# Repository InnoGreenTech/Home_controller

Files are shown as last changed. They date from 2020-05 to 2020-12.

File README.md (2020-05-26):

# Home_controller
Home controller allow to pilote the VMC.  For this it reads the CO2, Humidity and temperature. It is able also forecast the Weather. It have a touch screen.

Description:
------------

Home controller allow to pilote a VMC. It use a MH-Z19B sensor to measure the C02 and DHT22 for humidity and temperature in the pipe of the ventilation.
A BME280 allow to measure humidity, temperature and pressure in out door, like this is possible to forecaste weather.

There are a main card with a touch screen and a remote VMC.

Also ther is another modul to measure the power consomation of the house. Is it possible to read them in real time.

A optional ESP8266, allow to sent data with a Json file and it is possible to connect at a webpage with evry information.

[*You can found more information on my web site on this page*](https://innogreentech.fr/fr/objets-connectes/mesures/70-controleur-de-vmc)

I share also the drawing, the pcb, and the box designe in this repository.

Screen interface:
----------------
Picture of current status

Remote VMC:
----------------

Picture of current status

Remote energie meter:
----------------

Picture of current status

Contributing:
-------------

Fork it.
Create your feature branch (git checkout -b my-new-feature).
Commit your changes (git commit -am 'Add some feature').
Push to the branch (git push origin my-new-feature).
Create new Pull Request.

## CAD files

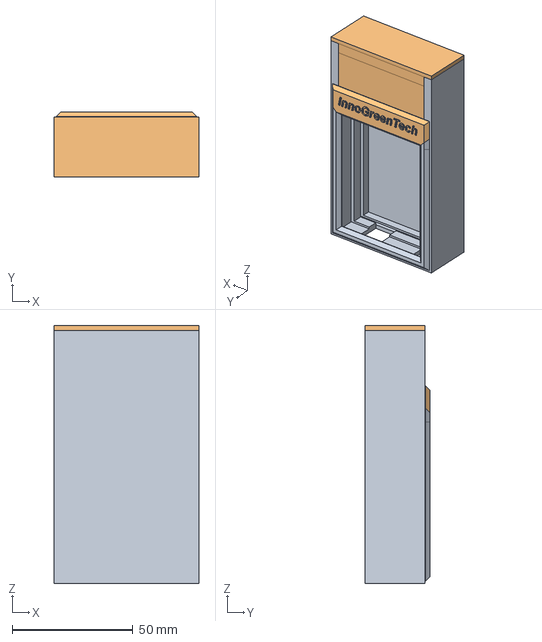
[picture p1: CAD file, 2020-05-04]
Main_board/Drawing and 3D files/box_main_card_home_controller.FCStd
60.0 x 27.0 x 107.0 mm
Bouchon

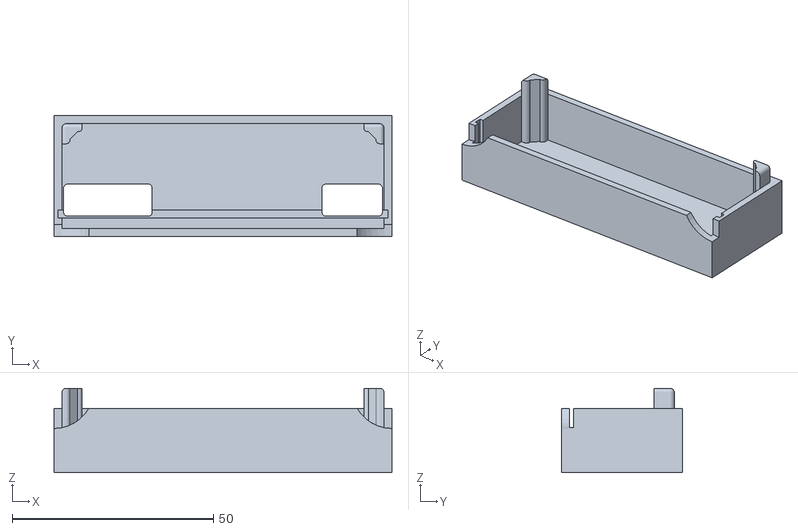
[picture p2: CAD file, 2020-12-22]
Board_VMC_home/3D_printer_files/Cache box carte VMC..stl
84.0 x 30.0 x 21.0

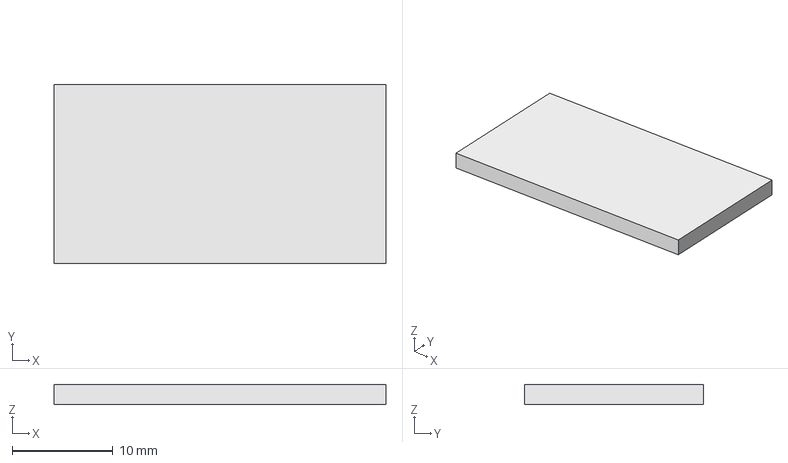
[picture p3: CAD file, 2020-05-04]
Energy_meter/Drawing_energy_meter/Fichier 3D/3D_compteur_energie.FCStd
33.0 x 17.8 x 2.00 mm

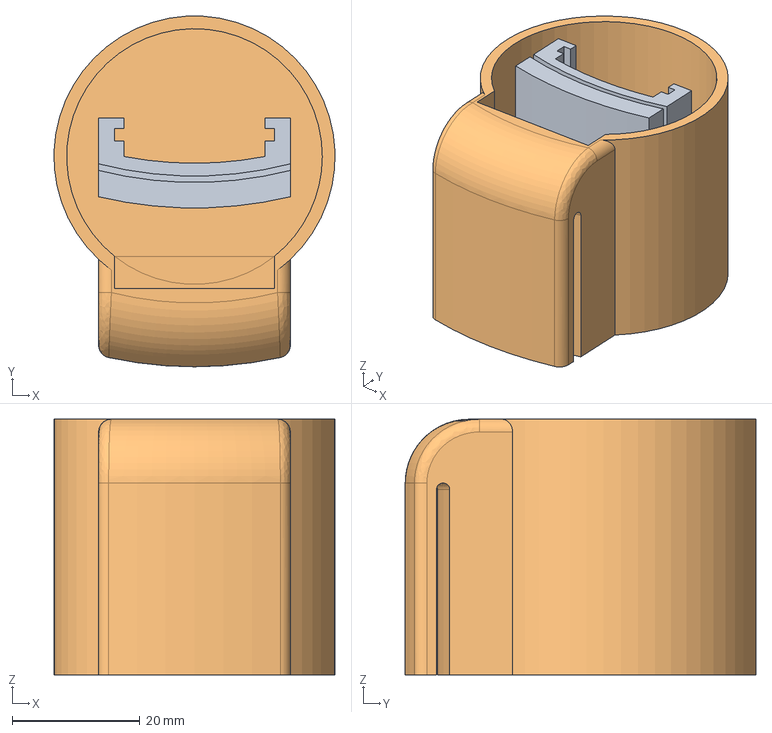
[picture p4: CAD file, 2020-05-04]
Board_VMC_home/3D_printer_files/probe_vmc_support.FCStd
44.0 x 54.9 x 40.0 mm

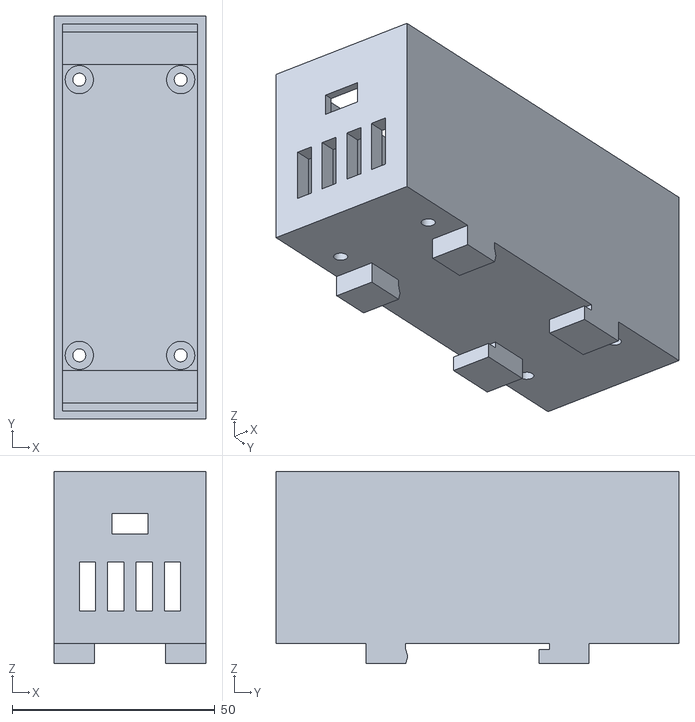
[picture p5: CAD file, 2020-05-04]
Energy_meter/Drawing_energy_meter/Fichier 3D/corp_module.stl
37.4 x 99.4 x 47.4

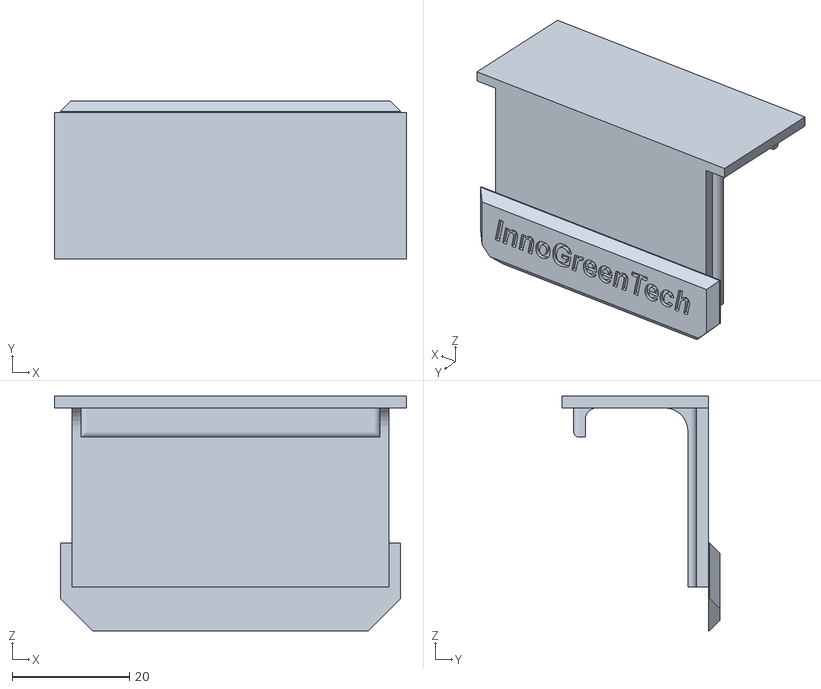
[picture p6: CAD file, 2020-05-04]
Main_board/Drawing and 3D files/closer_home_controller.stl
60.0 x 27.0 x 40.0

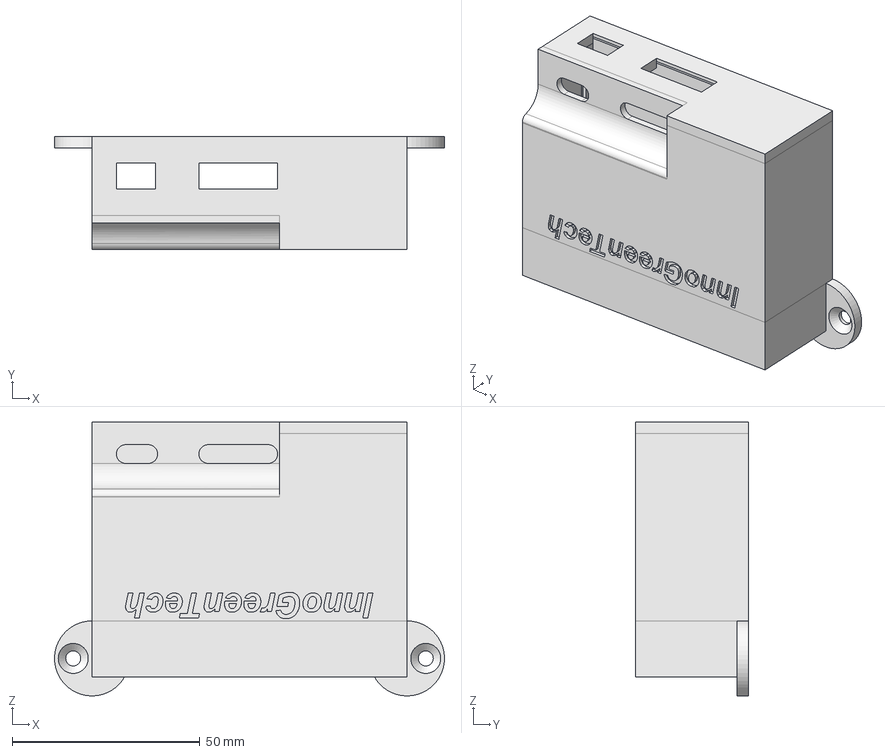
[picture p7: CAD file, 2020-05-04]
Board_VMC_home/3D_printer_files/vmc_card_box.FCStd
104.0 x 30.0 x 73.0 mm

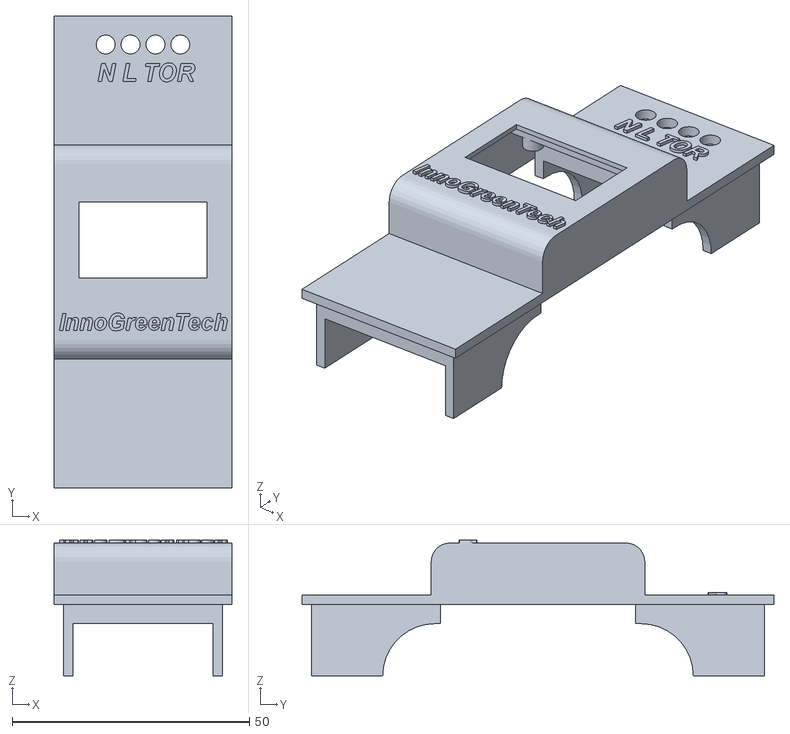
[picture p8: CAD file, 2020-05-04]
Energy_meter/Drawing_energy_meter/Fichier 3D/couvercle_module.stl
37.4 x 99.4 x 28.6

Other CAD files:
Board_VMC_home/3D_printer_files/VMC_card_box.stl
Board_VMC_home/3D_printer_files/probe_vmc_support.stl
Main_board/Drawing and 3D files/box_main_card_home_controller.stl

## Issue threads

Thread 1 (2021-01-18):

salut

cybermandiant, 2021-01-18:
salut super beau projet seulement je bloque sur la librairie manquante  <Fonts/WeatherIcon.h>
dans le dossier Main board le croqui ne veux pas ce compiler :( car il manque ce fichier

InnoGreenTech, 2021-01-21:
Bonjour,
Il faut récupérer le font ici: https://github.com/kaldoran/Adafruit-Weather-Icon/blob/master/WeatherIcon.h  Ensuite installer le fichier sous le répertoire Adafruit_GFX_Library\Fonts de la bibliothèque d'Ada-fruit.

cybermandiant, 2021-01-21:
Bonsoir super merci beaucoup pour la reponse :)

Closed 2021-01-21.

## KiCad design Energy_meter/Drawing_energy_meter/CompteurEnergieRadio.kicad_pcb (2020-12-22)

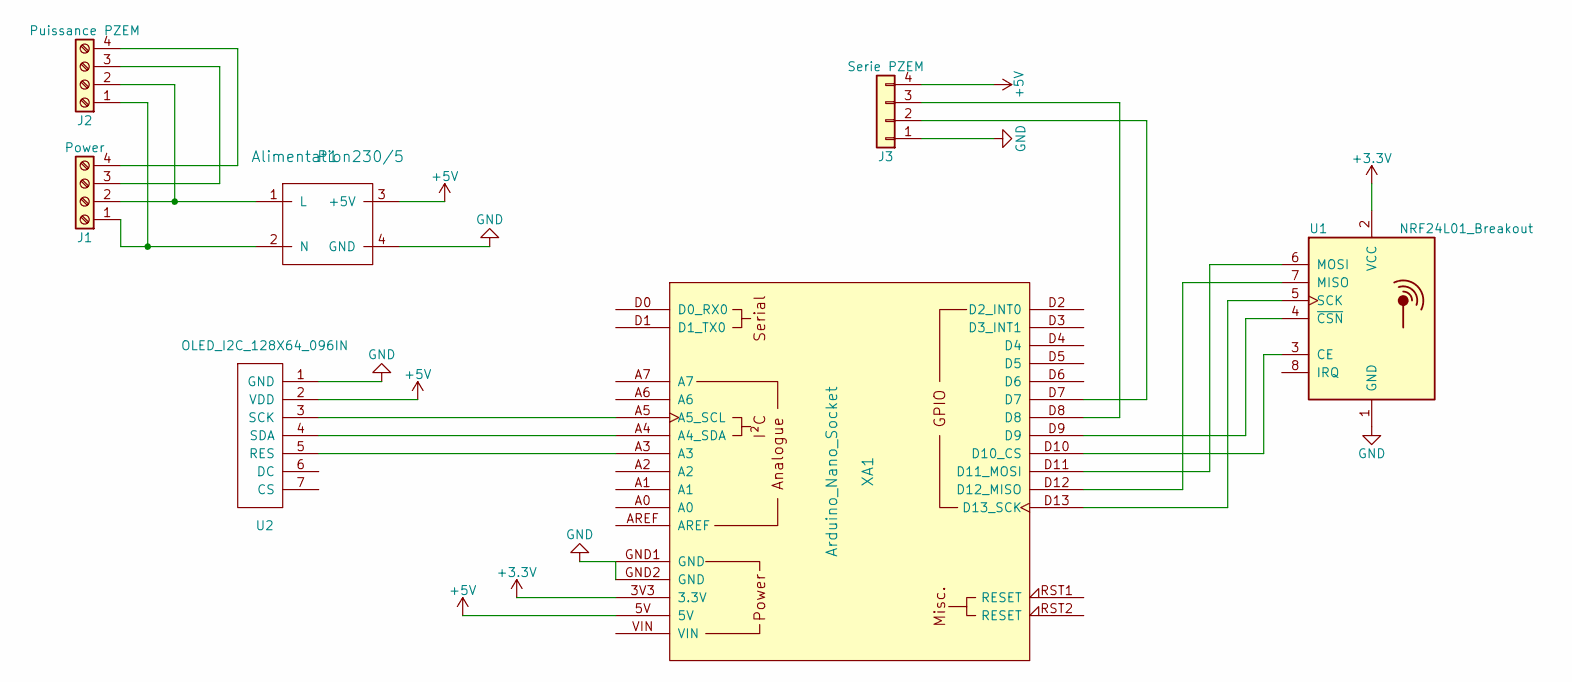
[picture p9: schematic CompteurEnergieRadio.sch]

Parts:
J1: Power; TerminalBlock_bornier-4_P5.08mm
J2: Puissance PZEM; TerminalBlock_bornier-4_P5.08mm
J3: Serie PZEM; JST_EH_B04B-EH-A_04x2.50mm_Straight
P1: Alimentation230/5; Alimentation5V
U1: NRF24L01_Breakout; nRF24L01_Breakout
U2: OLED_I2C_128X64_096IN; 96OLEDV2
XA1: Arduino_Nano_Socket; Arduino_Nano_2

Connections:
+3V3: U1.2 (VCC), XA1.3V3 (3.3V)
+5V: J3.4, P1.3 (+5V), U2.2 (VDD), XA1.5V
GND: J3.1, P1.4 (GND), U1.1 (GND), U2.1 (GND), XA1.GND1 (GND), XA1.GND2 (GND)
unnamed: J1.1, J2.1, P1.2 (N)
unnamed: J1.2, J2.2, P1.1 (L)
unnamed: J1.3, J2.3
unnamed: J1.4, J2.4
unnamed: J3.2, XA1.D7
unnamed: J3.3, XA1.D8
unnamed: U1.3 (CE), XA1.D10 (D10_CS)
unnamed: U1.4 (~CSN), XA1.D9
unnamed: U1.5 (SCK), XA1.D13 (D13_SCK)
unnamed: U1.6 (MOSI), XA1.D11 (D11_MOSI)
unnamed: U1.7 (MISO), XA1.D12 (D12_MISO)
unnamed: U2.3 (SCK), XA1.A5 (A5_SCL)
unnamed: U2.4 (SDA), XA1.A4 (A4_SDA)
unnamed: U2.5 (RES), XA1.A3

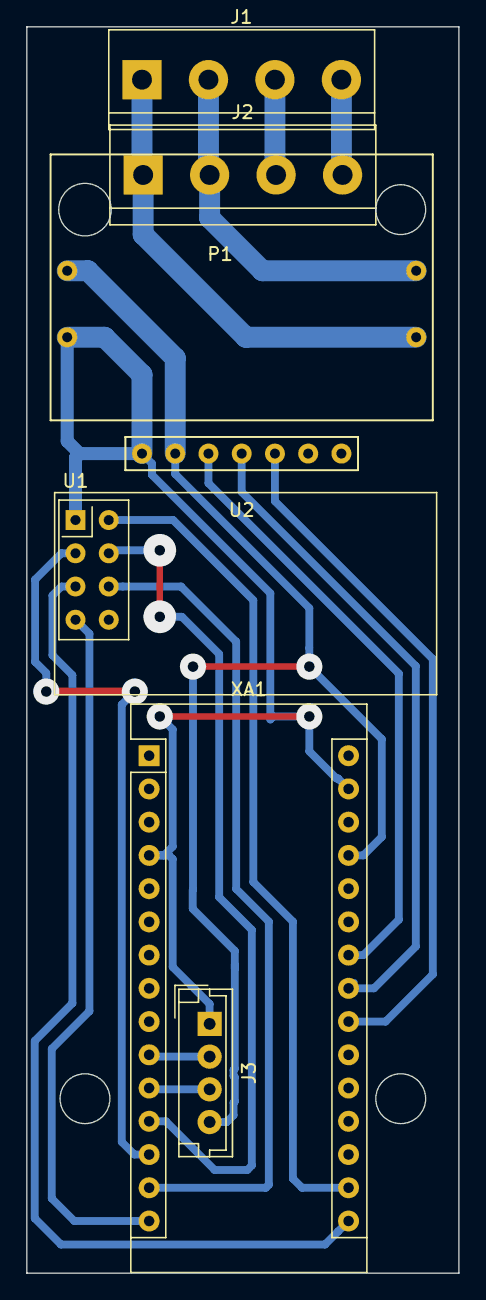
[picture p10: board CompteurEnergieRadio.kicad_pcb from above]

Board: 2 copper layers, 33.0 x 95.3 mm, 7 parts (0 on the bottom side), 17 nets.

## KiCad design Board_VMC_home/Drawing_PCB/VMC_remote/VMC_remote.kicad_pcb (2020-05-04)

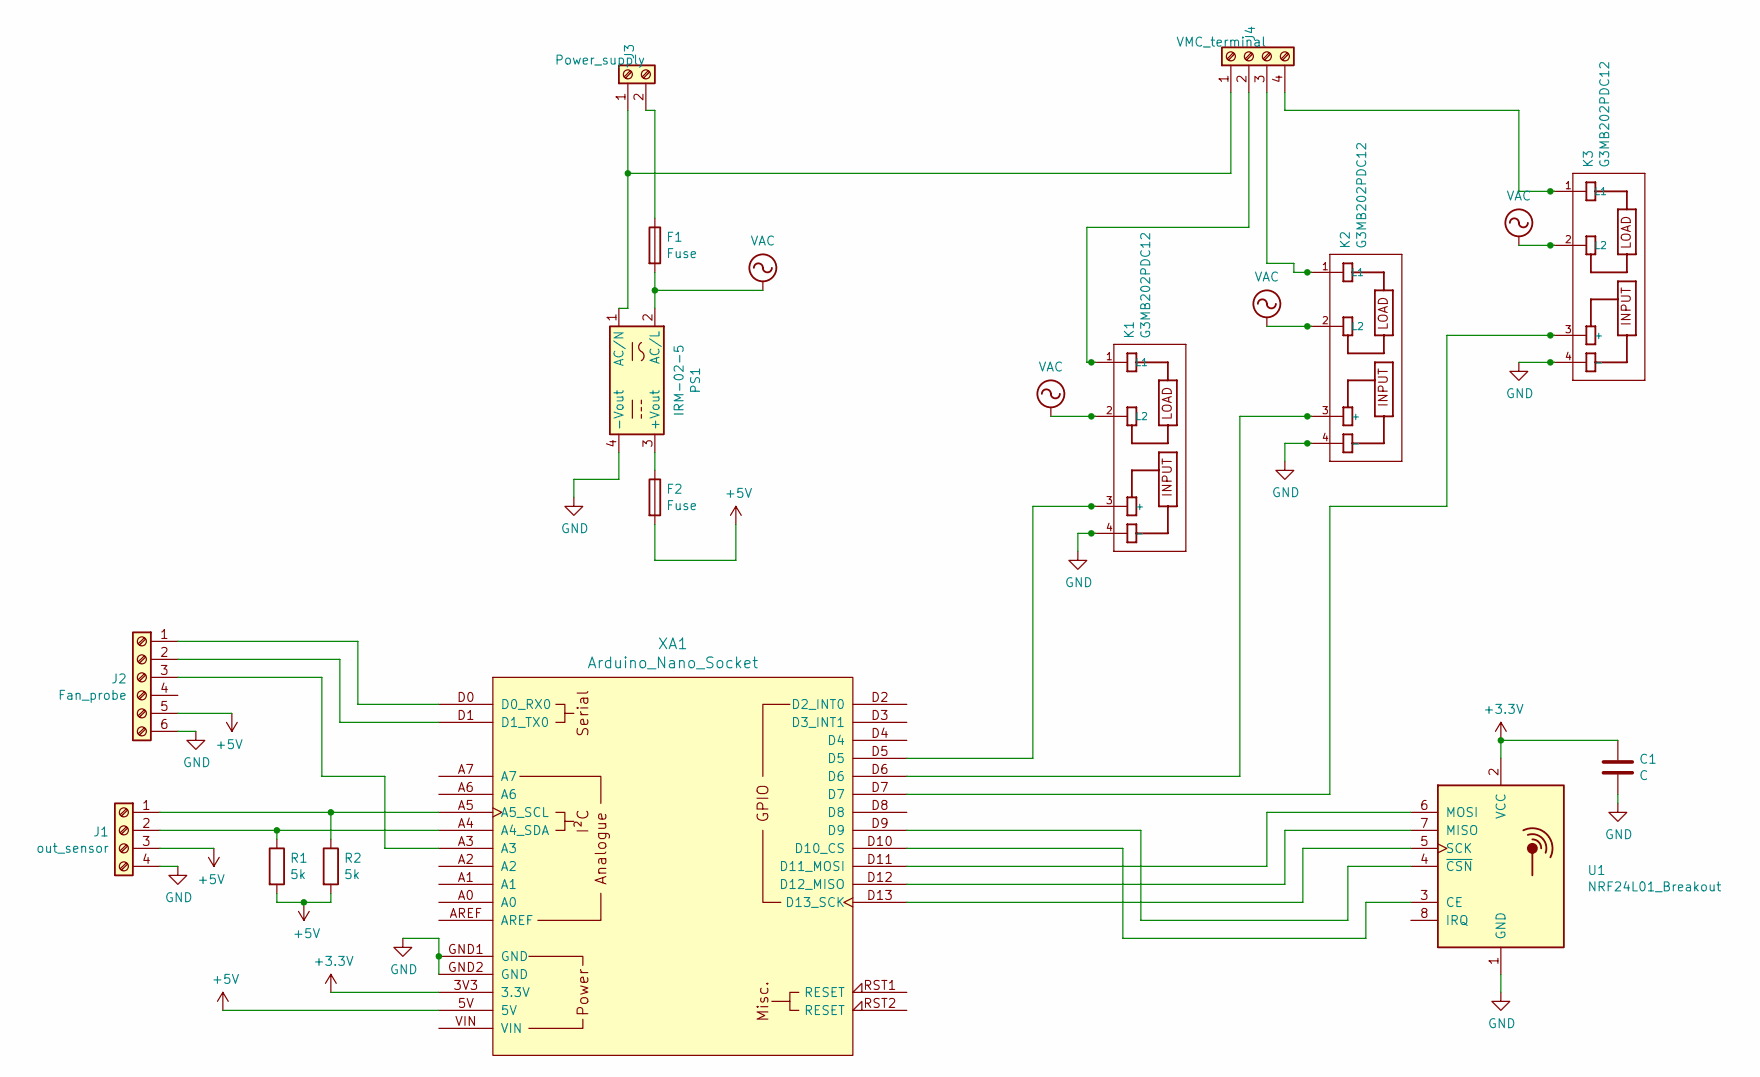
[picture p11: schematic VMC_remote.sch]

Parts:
C1: C; C_Disc_D7.0mm_W2.5mm_P5.00mm
F1, F2: Fuse; R_Axial_DIN0516_L15.5mm_D5.0mm_P20.32mm_Horizontal
J1: out_sensor; TerminalBlock_4Ucon_1x04_P3.50mm_Horizontal
J2: Fan_probe; TerminalBlock_4Ucon_1x06_P3.50mm_Horizontal
J3: Power_supply; TerminalBlock_bornier-2_P5.08mm
J4: VMC_terminal; TerminalBlock_bornier-4_P5.08mm
K1, K2, K3: G3MB202PDC12; RELAY_G3MB202PDC12
PS1: IRM-02-5; Converter_ACDC_MeanWell_IRM-02-xx_THT
R1, R2: 5k; R_Axial_DIN0411_L9.9mm_D3.6mm_P12.70mm_Horizontal
U1: NRF24L01_Breakout; nRF24L01_Breakout
XA1: Arduino_Nano_Socket

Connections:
+3V3: C1.1, U1.2 (VCC), XA1.3V3 (3.3V)
+5V: F2.2, J1.3, J2.5, R1.2, R2.2, XA1.5V
GND: C1.2, J1.4, J2.6, K1.4 (-), K2.4 (-), K3.4 (-), PS1.4 (-Vout), U1.1 (GND), XA1.GND1 (GND), XA1.GND2 (GND)
unnamed: F1.1, J3.2
unnamed: F2.1, PS1.3 (+Vout)
unnamed: J1.1, R2.1, XA1.A5 (A5_SCL)
unnamed: J1.2, R1.1, XA1.A4 (A4_SDA)
unnamed: J2.1, XA1.D0 (D0_RX0)
unnamed: J2.2, XA1.D1 (D1_TX0)
unnamed: J2.3, XA1.A3
unnamed: J3.1, J4.1, PS1.1 (AC/N)
unnamed: J4.2, K1.1 (L1)
unnamed: J4.3, K2.1 (L1)
unnamed: J4.4, K3.1 (L1)
unnamed: K1.3 (+), XA1.D5
unnamed: K2.3 (+), XA1.D6
unnamed: K3.3 (+), XA1.D7
unnamed: U1.3 (CE), XA1.D10 (D10_CS)
unnamed: U1.4 (~CSN), XA1.D9
unnamed: U1.5 (SCK), XA1.D13 (D13_SCK)
unnamed: U1.6 (MOSI), XA1.D11 (D11_MOSI)
unnamed: U1.7 (MISO), XA1.D12 (D12_MISO)
VAC: F1.2, K1.2 (L2), K2.2 (L2), K3.2 (L2), PS1.2 (AC/L)

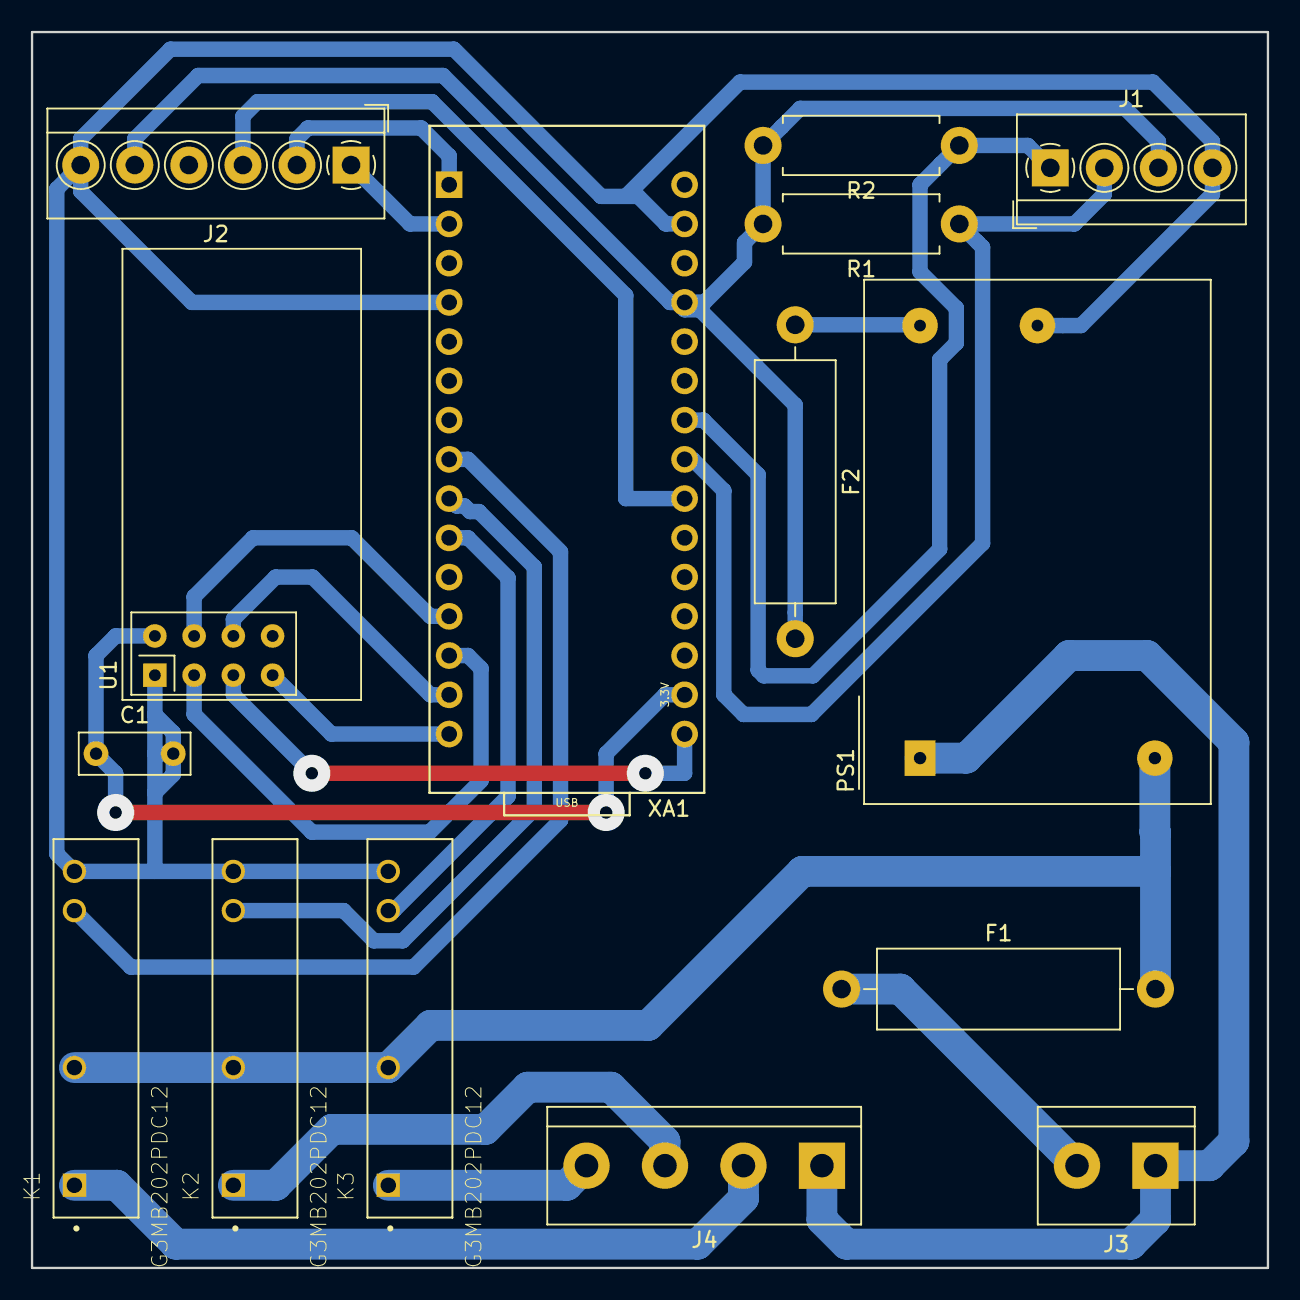
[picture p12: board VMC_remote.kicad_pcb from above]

Board: 2 copper layers, 80.0 x 80.0 mm, 15 parts (0 on the bottom side), 23 nets.

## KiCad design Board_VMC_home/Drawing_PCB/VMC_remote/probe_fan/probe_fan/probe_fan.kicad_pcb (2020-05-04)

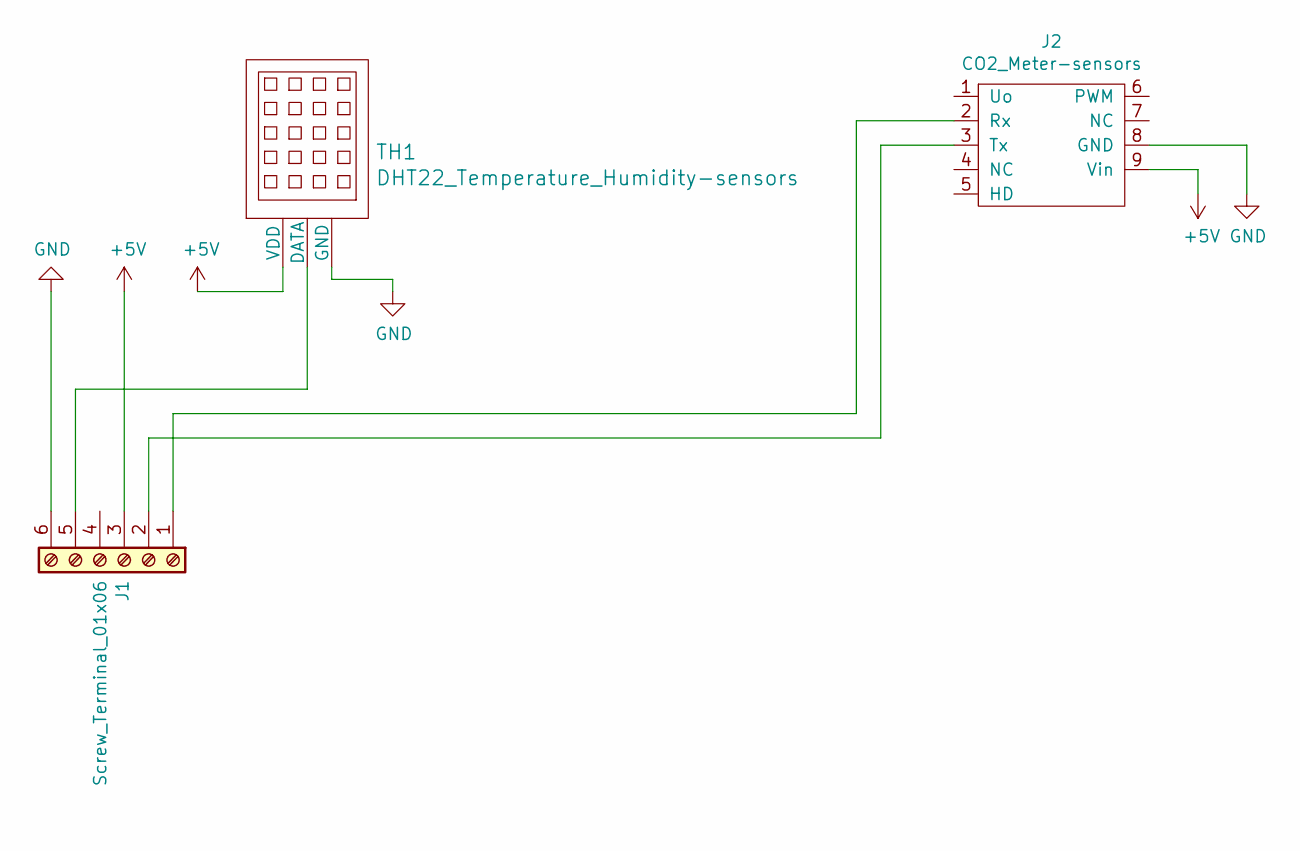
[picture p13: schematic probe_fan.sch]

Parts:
J1: Screw_Terminal_01x06; TerminalBlock_MetzConnect_Type059_RT06306HBWC_1x06_P3.50mm_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
J2: CO2_Meter-sensors; MHZ19B
TH1: DHT22_Temperature_Humidity-sensors; DHT22_Temperature_Humidity

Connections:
+5V: J1.3, J2.9 (Vin), TH1.1 (VDD)
GND: J1.6, J2.8 (GND), TH1.3 (GND)
unnamed: J1.1, J2.2 (Rx)
unnamed: J1.2, J2.3 (Tx)
unnamed: J1.5, TH1.2 (DATA)

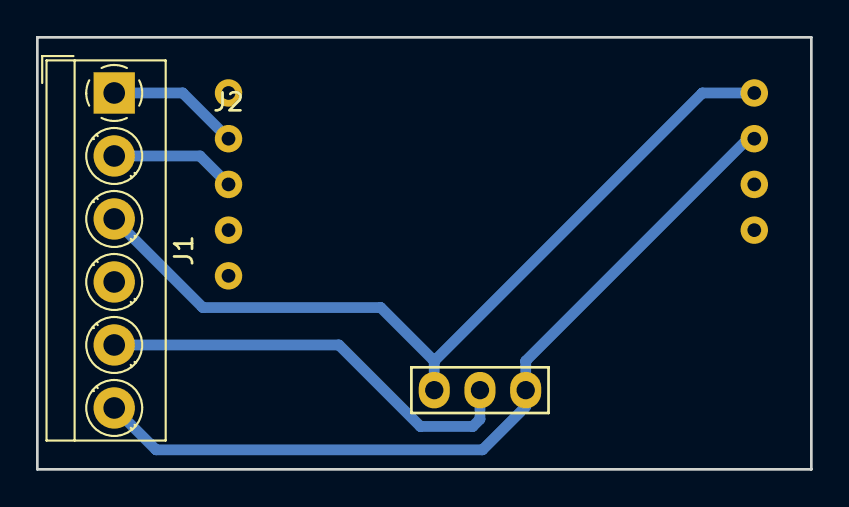
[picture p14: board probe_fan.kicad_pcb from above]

Board: 2 copper layers, 43.0 x 24.0 mm, 3 parts (0 on the bottom side), 5 nets.

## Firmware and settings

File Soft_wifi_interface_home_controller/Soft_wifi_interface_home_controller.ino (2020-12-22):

    #include <ESP8266WiFi.h>          //https://github.com/esp8266/Arduino
    #include <wchar.h> 
    #include <WString.h>
    #include <ESP8266WebServer.h>
    #include <DNSServer.h>
    #include <ESP8266Ping.h>
    #include <ESP8266HTTPClient.h>
    #include <ESP8266HTTPUpdateServer.h>
    
    #include <ArduinoJson.h>
    
    /*#include <Modbus.h>
    #include <ModbusIP_ESP8266.h>
    
    //Modbus Registers Offsets (0-9999)
    const int SENSOR_IREG = 100;

    ModbusIP mb;
    
    long ts; */
    
    #include <EEPROM.h> // Gestion de la mémoire de type eeprom pour la sauvegarde des choix
    
    #define ALARME_EEPROM   0   // Addresse de mémorisations des alarmes
    #define NAME_MODULE     1   //Name of module
    #define ADRESS_SERVER   22  // adress of server php
    #define PORT_SERVER     43  // Port of server
    #define PERIOD          50  // Period to send datas in seconds
    #define MEM_SSID        70
    #define MEM_PASSWORD    170 //
    
    
    #define TEMPERATURE_MAX     60    //Temperature maximum
    #define TEMPERATURE_MIN     62    //Température minimum
    #define TEMPERATURE_OFFSET  64 
    #define HUMIDITE_MAX        66    // Humidity relative maximum
    #define HUMIDITE_MIN        68    // Humidity relative minimum
    #define HUMIDITE_OFFSET     70
    #define LEVEL_MAX           72     // Level of water maximum
    #define LEVEL_MIN           74     // level of water min
    #define LEVEL_OFFSET        76
    #define COUNT_MAX        78    // Number of passages maximum
    #define COUNT_MIN        80    // Number of passages maximum 
    #define COUNT_OFFSET     82
    
    float tIn;      // Variable Température intérieur
    long hIn;      // Variable humidité intérieur
    long qIn;      // Variable de la qualité de l'air intérieur
    float tOut;     // Variable température extérieur
    long hOut;     // Variable humidité extérieur
    float pOut;
    long qOut;     // Variable de la qualité de l'air extérieur
    long venti;    // Valeur de la ventilation actuelle;
    
    float u;  // Tension du réseau électrique en volts
    int iU;
    float uT;  // U total
    
    float i;  // Courant consommée
    int iI;   // index for obtain the average
    float iT;
    
    long p; //Puissance instantanée consommée
    int iP;  // Index for obtain the average between both dispatch
    long pT;
    
    long e;   //Energie totale consommée
    float tsalon;    // Température du salon





    int period;                 // period to sent datas

    int index_sent=0;                           //allow to sent data one by one with PERIOD_SENT bettween each
    #define PERIOD_SENT 100                     //one information every 100 ms;
    unsigned long period_sent=0;                //control the last message
    unsigned long number_of_samples;            //Number of samples between two sender 


    String reception;          // Variable pour la réception sur le port série
    int code;                  // Variable code pour l'échange d'information
// Utilitaires pour la gestion des alarmes

    byte activation_alarmes; // Mot utilisé pour l'activation des alarmes
    byte alarmes_actives;     // Drapeau d'activation des alarmes
    int nbenvois=0;           //nombre d'envoi de mail
    
    #define ALARME_G  0  // Bit d'activation de la surveillance d'alarme
    #define ALARME_T  1  //Bit d' Activation des alarmes de température
    #define ALARME_H  2  // Bit d'activation des alarmes d'humidités
    #define ALARME_L  3   //Bit d'activation des alarmes de niveau d'eau
    #define ALARME_C  4   //Bit d'activation des alarmes de comptage
    
    unsigned long  lastmessage;         // heures d'envoi des derniers relevés
    unsigned long  millisecondes;       // Intervalle des relevés en millisecondes
    int nb_cycle_lost_wifi=0;           // test before reboot when the wifi is lost
    
    #define NB_TRYING_CONNECT 4         
    
    
    
    int t_max; // Seuil de déclenchement de la température maximum
    int t_min;  // seuil de déclenchement de la température minimum
    int t_offset;
    int h_max;     // seuil de l'humidité maximum
    int h_min;     // humidité de l'humidité minimump
    int h_offset;
    int l_max;    //niveau maximum
    int l_min;    //niveau minimum
    int l_offset;
    int c_max;    // seuil du nombre de personnes passées
    int c_min;    // seuil du nombre de personnes passées
    int c_offset; 

/* String for commnunication */

    char          name_module[20];          // name of module
    String        ref_module;               // référence du module
    String        version_module;           // version of module
    char          ip_server[15];            // adress ip of the module
    int unsigned  port_server;              // port of server
    String        local_mac;                // adress mac of the module
    String        local_ip;                 // adress ip of module
    String        gate_way;
    String        date;             
    String        currently_time; 


/*********************************************************
 *  Key of communication between Arduino and ESP8266     *
 *********************************************************/


    #define CODE_COMMAND_INFO                           "$I$"
    #define CODE_COMMAND_READ                           "$R$" 
    #define CODE_COMMAND_WRITE                          "$W$" 

    #define         CODE_TENSION                  10
    #define         CODE_COURANT                  11
    #define         CODE_PUISSANCE                12
    #define         CODE_CONSOMMATION             13
    #define         CODE_TEMPERATURE_OUT          14
    #define         CODE_HUMIDITY_OUT             15
    #define         CODE_PRESSURE                 30
    #define         CODE_TEMPERATURE_IN           16
    #define         CODE_HUMIDITY_IN              17
    #define         CODE_CO2                      18
    #define         CODE_SPEED_FAN                19
    #define         CODE_MODE                     28
    #define         CODE_SET_TEMPERATURE_SUMMER   23
    #define         CODE_SET_TEMPERATURE_WINTER   24
    #define         CODE_SET_HUMIDITY_SUMMER      25
    #define         CODE_SET_HUMIDITY_WINTER      26
    #define         CODE_SET_CO2                  27
    #define         CODE_SET_ALTITUDE             29
    #define         CODE_DATE                     31      // Code de la date actuell
    #define         CODE_HEURE                    32      //Code de l'heure actuelle
    #define         CODE_IP                       33      // Adresse IP de connexion
    #define         CODE_GATE_WAY                 34      // Code pour la passerelle
    #define         CODE_MAC                      35      // Adresse MAC du modul wifi

    ESP8266WebServer server(80); // on instancie un serveur ecoutant sur le port 80
    
    String ssid="";
    String password="";
    int    config_mode=0;
    unsigned long delay_reboot;       // delay during the page of connection is open befor reboot
    #define DELAY_REBOOT 120000 
    
    #include <TimeLib.h>       // Use for take date in internet
    #include <NtpClientLib.h>
    
/* setting to update server */

    const char* update_path = "/firmware";
    const char* update_username = "innogreentech";
    const char* update_password = "innogreentech";
    

    ESP8266HTTPUpdateServer httpUpdater;

  

void setup() {

              /* Mod bus configuration

              mb.config("your_ssid", "your_password");
              mb.addIreg(SENSOR_IREG); */
            
              /* Récupération des données mémorisées:*/
              Serial.begin(115200);
              Serial.setDebugOutput(0);
            
              EEPROM.begin(512);                              // allocations  de 512 adresses Mémoires
            
             
              activation_alarmes=EEPROM.read(ALARME_EEPROM); // lecture du réglage des alarmes
              
              char carac='1';   // Name of module
              int a=0;
              while (!(carac=='\0')&&a<20){carac=char (EEPROM.read(NAME_MODULE+a));reception+= carac; a++;} 
              if (reception=='\0'||a==20){reception=F("InnoGreenTech");}
              int c = reception.length() + 1;                               // longueur de la chaîne de caractéres
              reception.toCharArray(name_module, c); 
             // Serial.println(name_module);        
              
              reception="";    // read memory ip adress server
              carac='1';
              a=0;
              while (!(carac=='\0')&&a<20){carac=char (EEPROM.read(ADRESS_SERVER+a));reception+= carac; a++;}
              if (reception=='\0'||a==20){reception=F("InnoGreenTech");} 
              c = reception.length() + 1;       
              reception.toCharArray(ip_server, c);
              //  Serial.println(ip_server);
              

                

            
              byte mem[2];
              for (int a=0;a<3;a++){mem[a]= EEPROM.read(PORT_SERVER+a);}     // load the port server         
              port_server= mem[0]|mem[1]<<8;
              
              for (int a=0;a<3;a++){mem[a]= EEPROM.read(PERIOD+a);}          // load the time period
              period= mem[0]|mem[1]<<8;
              millisecondes=period*1000;

              
              for (int a=0;a<3;a++){mem[a]= EEPROM.read(TEMPERATURE_MAX+a);}          // Récupération de la température Max
              t_max= mem[0]|mem[1]<<8;                                                
              for (int a=0;a<3;a++){mem[a]= EEPROM.read(TEMPERATURE_MIN+a);}          // Récupération de la température Minimum
              t_min= mem[0]|mem[1]<<8;
              for (int a=0;a<3;a++){mem[a]= EEPROM.read(TEMPERATURE_OFFSET+a);}  
              t_offset= mem[0]|mem[1]<<8;
               
              for (int a=0;a<3;a++){mem[a]= EEPROM.read(HUMIDITE_MAX+a);}             // Récupération de l'hummpidité maximum
              h_max= mem[0]|mem[1]<<8; 
              for (int a=0;a<3;a++){mem[a]= EEPROM.read(HUMIDITE_MIN+a);}             // Récupération de l'hummpidité minimum
              h_min= mem[0]|mem[1]<<8;
              for (int a=0;a<3;a++){mem[a]= EEPROM.read(HUMIDITE_OFFSET+a);}  
              h_offset= mem[0]|mem[1]<<8;
               
              for (int a=0;a<3;a++){mem[a]= EEPROM.read(LEVEL_MAX+a);}               // Récupération du niveau maximum
              l_max= mem[0]|mem[1]<<8; 
              for (int a=0;a<3;a++){mem[a]= EEPROM.read(LEVEL_MIN+a);}               // Récupération du niveau minimum
              l_min= mem[0]|mem[1]<<8;
              for (int a=0;a<3;a++){mem[a]= EEPROM.read(LEVEL_OFFSET+a);}  
              l_offset= mem[0]|mem[1]<<8;


               
              for (int a=0;a<3;a++){mem[a]= EEPROM.read(COUNT_MAX+a);}             // Récupération du seuil du nombre de passage
              c_max= mem[0]|mem[1]<<8;
              for (int a=0;a<3;a++){mem[a]= EEPROM.read(COUNT_OFFSET+a);}  
              c_offset= mem[0]|mem[1]<<8; 

              carac='1';                
              a=0;
              while (!(carac=='\0')&&a<100){carac=char (EEPROM.read(MEM_SSID+a));
              if (!(carac=='\0')){ssid +=carac;} a++;}  //récupération du lien d'information
              if (ssid=='\0'||a>50){ssid=F("");}
            
              carac='1';
              a=0;
              while (!(carac=='\0')&&a<100){carac=char (EEPROM.read(MEM_PASSWORD+a));
              if (!(carac=='\0')){password +=carac;} a++;}  //récupération du lien d'information
              if (password=='\0'||a>50){password=F("");}




           /*Connexion wifi*/
           
           WiFi.mode(WIFI_STA);
           
           c =ssid.length()+1;
           char char_ssid[50];
           ssid.toCharArray(char_ssid, c);

           c =password.length()+1;
           char char_password[50];
           password.toCharArray(char_password, c);

        
           WiFi.begin(char_ssid,char_password);
           
             unsigned long time_out_connection = millis();
              while (WiFi.status() != WL_CONNECTED)
              {
                if (millis() - time_out_connection > 20000)
                {
                  Serial.println F("");
                  Serial.println F ("connection Wifi fail !");
            
                  break;
                }
                delay(100);
                Serial.print('-');
              }
           
           if ( WiFi.status()!= WL_CONNECTED)
        
              {
                Serial.println F ("Open setting gate !");
                WiFi.disconnect();
                WiFi.mode(WIFI_AP); 
                delay(200);
                WiFi.softAP("InnoGreenTech", "innogreentech");
                server.on ( "/index.html", handleRoot );    // go to set up wifi page
                delay(100);
                server.on ("/style.css", cssRoot);     // envoi au fichier de configuration de style
                local_mac = WiFi.macAddress();
                delay(100);
                server.begin();

              
              }

             else

             {
           
              
              /*Read the houre and date on internet */
            
              NTP.begin("pool.ntp.org", 1, true);  //configuration de la récupération de la date,  Serveur+1 heure, Heure été/hivers
              NTP.setInterval(3600);                // Toutes les heures
                      
              /*information of module*/

              local_ip=WiFi.localIP().toString().c_str();              
              local_mac=WiFi.macAddress();//.toString().c_str();
              gate_way=WiFi.gatewayIP().toString().c_str();
              ref_module="Greenhouse";
              version_module="V1";

              Serial.print(F("référence:"));Serial.println(ref_module);
              Serial.print(F("Version:"));Serial.println(version_module);
              Serial.print(F("Adresse IP:"));Serial.println(local_ip);
              Serial.print(F("Adresse MAC:"));Serial.println(local_mac); 
              Serial.println(WiFi.gatewayIP());
              Serial.println(WiFi.dnsIP(1)); 
                          
              /* Configuration du serveur Web */
              
              server.on ( "/index.html", indexRoot );    // Renvoi à la page de index
               delay(100);
              server.on ( "/", indexRoot );    // Renvoi à la page de index
               delay(100);
              server.on ( "/add_module.csv", add_module );    // Page for add or modify  module by php server 
               delay(100);
              server.on ( "/config_probe.htlm", config_probe );    // Page for do a configuration of probes by php server
               delay(100);
              server.on ("/style.css", cssRoot);     // envoi au fichier de configuration de style
               delay(100);
              httpUpdater.setup(&server, update_path, update_username, update_password);

             }
              
              /*listen on the server*/
              
              server.begin();

              
              }


void loop() {

            server.handleClient();
            recep_data();
            send_information();
            if (millis()>lastmessage+millisecondes){send_data();}
  
            }

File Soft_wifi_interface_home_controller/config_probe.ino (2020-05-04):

void config_probe(){

      int id_probe=0;


      if ( server.hasArg("id_prob") ) 
              {      
              reception=server.arg("id_prob");
              id_probe=reception.toInt();
              }
      else {return;}         


      if (id_probe==1)
            { 
              if ( server.hasArg("off_set") )
              {
              reception = server.arg("off_set");
              t_offset=reception.toInt();
              int b=h_offset;
              for (int a=0;a<2;a++){EEPROM.write(TEMPERATURE_OFFSET+a ,b);b=b>>8;}
              } 

            
              if ( server.hasArg("max") )
              {
              reception = server.arg("max");
              t_max=reception.toInt();
              int b=t_max;
              for (int a=0;a<2;a++){EEPROM.write(TEMPERATURE_MAX+a ,b);b=b>>8;}
              }   

              if ( server.hasArg("min") )
              {
              reception = server.arg("min");
              t_min=reception.toInt();
              int b=t_min;
              for (int a=0;a<2;a++){EEPROM.write(TEMPERATURE_MIN+a ,b);b=b>>8;} 
              } 

              if ( server.hasArg("alarm") )
              {
              reception=server.arg("alarm");
              if (reception.equals("1")) {bitSet(activation_alarmes, ALARME_T);}  // Active alarm
              else {bitClear(activation_alarmes, ALARME_T);}                       
              EEPROM.write(ALARME_EEPROM, activation_alarmes); 
              }
            }    
        

      if (id_probe==2)
           { 
              if ( server.hasArg("offset") )
              {
              reception = server.arg("offset");
              h_offset=reception.toInt();
              int b=h_offset;
              for (int a=0;a<2;a++){EEPROM.write(HUMIDITE_OFFSET+a ,b);b=b>>8;}
              } 
            
              if ( server.hasArg("max") )
              {
              reception = server.arg("max");
              h_max=reception.toInt();
              int b=h_max;
              for (int a=0;a<2;a++){EEPROM.write(HUMIDITE_MAX+a ,b);b=b>>8;}
              }   

              if ( server.hasArg("min") )
              {
              reception = server.arg("min");
              h_min=reception.toInt();
              int b=h_min;
              for (int a=0;a<2;a++){EEPROM.write(HUMIDITE_MIN+a ,b);b=b>>8;} 
              }

              
              if ( server.hasArg("alarm") )
              {
              reception=server.arg("alarm");
              if (reception.equals("1")) {bitSet(activation_alarmes, ALARME_H);}  // Active alarm
              else {bitClear(activation_alarmes, ALARME_H);}                       
              EEPROM.write(ALARME_EEPROM, activation_alarmes); 
              }                            
           }

     if (id_probe==4)
           { 
              if ( server.hasArg("offset") )
              {
              reception = server.arg("offset");
              c_offset=reception.toInt();
              int b=c_offset;
              for (int a=0;a<2;a++){EEPROM.write(COUNT_OFFSET+a ,b);b=b>>8;}
              } 
            
              if ( server.hasArg("max") )
              {
              reception = server.arg("max");
              c_max=reception.toInt();
              int b=c_max;
              for (int a=0;a<2;a++){EEPROM.write(COUNT_MAX+a ,b);b=b>>8;}
              }   

              if ( server.hasArg("min") )
              {
              reception = server.arg("min");
              c_min=reception.toInt();
              int b=c_min;
              for (int a=0;a<2;a++){EEPROM.write(COUNT_MIN+a ,b);b=b>>8;} 
              }

              
              if ( server.hasArg("alarm") )
              {
              reception=server.arg("alarm");
              if (reception.equals("1")) {bitSet(activation_alarmes, ALARME_C);}  // Active alarm
              else {bitClear(activation_alarmes, ALARME_C);}                       
              EEPROM.write(ALARME_EEPROM, activation_alarmes); 
              }                        
           }
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

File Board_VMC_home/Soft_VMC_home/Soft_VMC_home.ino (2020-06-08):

 /************************************************************************************
    
    <VMC speed main board control,>
    Copyright (C) <2019>  <Fabrice BAUDIN>

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
    info@InnoGreenTech.fr

****************************************************************************************//*******************************
/************************************************
 * Watch doog
 *********************************************/

    #include <avr/wdt.h>                

 
/************************
 *    EEPROM  ADDRESS   *
 ************************/

    #include <EEPROM.h>
    
    #define MEM_MODE                         0   // adresse sauvegarde set_mode_MEM
    #define MEM_SETTING_SUMMER_TEMPERATURE   4   // adresse sauvegarde consigne température ETE
    #define MEM_SETTING_WINTER_TEMPERATURE   8   // adresse sauvegarde consigne température hivers
    #define MEM_SETTING_SUMMER_HUMIDITY     12   // adresse sauvegarde consigne Humidité ETE
    #define MEM_SETTING_WINTER_HUMIDITY     16   // adresse sauvegarde consigne   Humidité Hive
    #define MEM_SETTING_CO2                 20   // Adresse sauvegarde consigne  qualité de l'aire
    #define MEM_SETTING_ALTITUDE            24   // Altitude memory



/*******************************
 *     Set modul radio         *
 *******************************/


    #include <nRF24L01.h>
    #include <printf.h>
    #include <RF24.h>
    #include <RF24_config.h>
    #define CERF 10             // Définition de la pin Enable
    #define CSRF 9              // Définition de la pin Sélection,
    RF24 radio(CERF,CSRF);      // Entrée des informations dans la librairie
    
    byte trans[5];              // Tableau pour la trans mission de données
    long donnee;                // Valeur de la donnée transmise
    byte nature;                // lecture de la nature de la demande de la carte mére




/*********************************************************************
 *                          setting sensor                           *
 *********************************************************************/
    
    #include <DHT.h>
    #include <DHT_U.h>
    #define DHT_IN_PIN  A3 // Branchement des données sur le port A3
    
    #define DHTTYPE DHT22 // Type de capteur (DHT 22 Pour capteurDHT 22)

    
    DHT dht_in(A3,DHTTYPE); //Définition de la sonde intérieur
    
    float tIn=99; // Variable Température intérieur
    long  hIn=99; // Variable humidité intérieur
    long  qIn=400;

    #include "SparkFunBME280.h"
    #include "Wire.h"            
    #include "SPI.h"
    
    BME280  bme_out;
    
    float tOut=99; //Variable température extérieure
    long  hOut=99; // Variable humidité extérieure
    long  pOut=10000; // 

    long venti=1; //Valeur la ventilation actuelle( 0= Arrêt; 1;2;3)
    long venti_last=0; // fan speed before new scheck
    long vt; // vitesse théorique demandée pour la régulation de  température (de 0 à  3)
    long vh; // vitesse  théorique pour la régulation de l'humidité
    long vq; // vitesse théorique pour la régulation de la qualité de lair

    byte commande; // lecture de la nature de la demande de la carte Vset_mode

    float set_temperature_summer; // consigne de température
    float set_temperature_winter; // consigne de température
    long  set_humidity_summer; // consigne d'humidité été
    long  set_humidity_winter; // consigne d'humidité hiver
    long  set_co2;// consigne de qualité d'air
    long  set_mode;//mode de fonctionnement
    long  set_altitude;
    long  consigne; //Lecture de la mesure
    unsigned long aquisition=0; // variable pour faire une aquisition toute les 2 secondes

    
   #define R1 5 // Relay vitesse 1
   #define R2 6 // Relay vitesse 2
   #define R3 7 // Relay vitesse 3
    

/*********************************************************
 *  Key of communication between Arduino                 *
 *********************************************************/


    #define CODE_COMMAND_INFO                           "$I$"
    #define CODE_COMMAND_READ                           "$R$" 
    #define CODE_COMMAND_WRITE                          "$W$" 

    #define         CODE_TENSION                  10
    #define         CODE_COURANT                  11
    #define         CODE_PUISSANCE                12
    #define         CODE_CONSOMMATION             13
    #define         CODE_TEMPERATURE_OUT          14
    #define         CODE_HUMIDITY_OUT             15
    #define         CODE_PRESSURE                 30
    #define         CODE_TEMPERATURE_IN           16
    #define         CODE_HUMIDITY_IN              17
    #define         CODE_CO2                      18
    #define         CODE_SPEED_FAN                19
    #define         CODE_MODE                     28
    #define         CODE_SET_TEMPERATURE_SUMMER   23
    #define         CODE_SET_TEMPERATURE_WINTER   24
    #define         CODE_SET_HUMIDITY_SUMMER      25
    #define         CODE_SET_HUMIDITY_WINTER      26
    #define         CODE_SET_ZERO_CO2             27
    #define         CODE_SET_CO2                  20
    #define         CODE_SET_ALTITUDE             29
    #define         CODE_DATE                     31      // Code de la date actuell
    #define         CODE_HEURE                    32      //Code de l'heure actuelle
    #define         CODE_IP                       33      // Adresse IP de connexion
    #define         CODE_GATE_WAY                 34      // Code pour la passerelle
    #define         CODE_MAC                      35      // Adresse MAC du modul wifi

    /*#include <SoftwareSerial.h>

    
#define MH_Z19_RX D7
#define MH_Z19_TX D6

SoftwareSerial co2Serial(MH_Z19_RX, MH_Z19_TX);*/
    



void setup() {

/******************************************
 *                Output setting          *
 *****************************************/

  pinMode(R1,OUTPUT);               // relais vitesse 1
  digitalWrite(R1,LOW);
  pinMode(R2,OUTPUT);               // relais vitesse 2
  digitalWrite(R2,LOW);
  pinMode(R3,OUTPUT);               // relais vitesse 3
  digitalWrite(R3,LOW);
 
  Serial.begin(9600); //configuration pour le port série (console)

/*******************************************
 *              probe setting              *
 * *****************************************/

  dht_in.begin(); // Mise en servic de la sonde de température et humidité intérieur
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

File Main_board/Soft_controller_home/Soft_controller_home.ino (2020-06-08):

 /************************************************************************************
    
    <VMC speed control, remote>
    Copyright (C) <2019>  <Fabrice BAUDIN>

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
    info@InnoGreenTech.fr

****************************************************************************************//*******************************/

/*******************************
 *     Utility library         *
 *******************************/
    
    
    #include <registers.h>          
    #include <pin_magic.h>
    #include  <printf.h>
    
/*******************************
 *     Set modul radio         *
 *******************************/
 
    #include  <nRF24L01.h>
    #include  <RF24.h>
    #include  <RF24_config.h>
    #define   CERF 49               
    #define   CSRF 48 
    RF24 radio(CERF,CSRF);      // define object
    
    byte trans[5] ;             // arrow for datas
    long donnee;                // data
    byte type_requiest;                // type of requiest

/************************
 *    EEPROM  ADDRESS   *
 ************************/

    #include <EEPROM.h>
    
    #define MEM_MODE                         0   // adresse sauvegarde MC_MEM
    #define MEM_SETTING_SUMMER_TEMPERATURE   4   // adresse sauvegarde consigne température ETE
    #define MEM_SETTING_WINTER_TEMPERATURE   8   // adresse sauvegarde consigne température hivers
    #define MEM_SETTING_SUMMER_HUMIDITY     12   // adresse sauvegarde consigne Humidité ETE
    #define MEM_SETTING_WINTER_HUMIDITY     16   // adresse sauvegarde consigne   Humidité Hive
    #define MEM_SETTING_CO2                 20   // Adresse sauvegarde consigne  qualité de l'aire
    #define MEM_SETTING_ALTITUDE            24   // Altitude memory

    
/**************************
 *      Screen setting    *
 **************************/

    #include <Adafruit_GFX.h>       // Librairie pour dessin
    #include <Adafruit_TFTLCD.h>    //librairie de configuration écran
    #include <Fonts/WeatherIcon.h>

    
    /* Pin setting */
    
    #define LCD_CS A3             // Chip Select goes to Analog 3
    #define LCD_CD A2             // Command/Data goes to Analog 2
    #define LCD_WR A1             // LCD Write goes to Analog 1
    #define LCD_RD A0             // LCD Read goes to Analog 0
    #define LCD_RESET A4          // Peut être raccordé à la pin reset de l'arduino


    /* Define colors */
    #define RGB565(R,G,B) ((((unsigned int)R&0xF8)<<8) | (((unsigned int)G&0xFC)<<3) | ((unsigned int)B>>3))  // Macro to convert couleur 24 bit

    #define BLACK   0x0000
    #define BLUE    0x001F
    #define RED     0xF800
    #define GREEN   0x07E0
    #define CYAN    0x07FF
    #define MAGENTA 0xF81F
    #define YELLOW  0xFFE0
    #define ORANGE  0xFD20 
    #define WHITE   0xFFFF
    #define BROWN   RGB565(165,175,143)
    
    #define FOND    0x0000        // Back colors

    Adafruit_TFTLCD tft(LCD_CS, LCD_CD, LCD_WR, LCD_RD, LCD_RESET);


/**********************************
*            Create buttons       *
***********************************/


    
    Adafruit_GFX_Button four_buttons[4];                     //création de 4 boutons pour l'écran d'accueil
    char main_buttons[4][4]={"IN","OUT","POW","INF"};    //nom des boutons de la page d'acceuil
    
    #define INF 3                                      // bouton de paramétrage
    #define IN  0                                      // VMC Page
    #define OUT  1                                      // Bouton de réglage de l'humidité
    #define POW  2                                      // Bouton d'accés au réglage de la qualité de l'air
  
    char setting_buttons[4][4]={" + ","OK"," - ","ESC"};
    #define LESS  2             // Button Moins
    #define OK    1             // Button OK
    #define MORE  0             // Button PLUS
    #define ESC   3             // Button END

    
    Adafruit_GFX_Button two_buttons[2];
    
    char second_buttons[2][8]={"Escape","Setting"}; 
    #define ESCAPE      0           // Button for screen of greenhouse
    #define SETTING     1           // Button for screen of compost

    char choice_buttons[2][5]={"UP","DOWN"}; 
    #define UP          0           // Button for screen of greenhouse
    #define DOWN        1           // Button for screen of compost

    Adafruit_GFX_Button six_buttons[6]; 
                      
    char mode_buttons[6][6]={"Stop","Hiver","Ete","V1","V2","V3"};
    
    #define STOP_VMC                      0           
    #define WINTER_MODE                   1           
    #define SUMMER_MODE                   2           
    #define SPEED_1                       3           
    #define SPEED_2                       4          
    #define SPEED_3                       5         


/*************************
 *   Set touch screen    *
 *************************/
     
    #include <TouchScreen.h>          
    
    #define YP A3                     // must be an analog pin, use "An" notation!
    #define XM A2                     // must be an analog pin, use "An" notation!
    #define YM 9                      // can be a digital pin
    #define XP 8                      // can be a digital pin
    
    #define TS_MINX 70                // Valeur minimun de la position en x
    #define TS_MAXX 920               // Valeur maximum de la position en x
    #define TS_MINY 70                // Valeur Minimum de la position en Y
    #define TS_MAXY 920               // Valeur maximum de la position en z
    
    TouchScreen ts = TouchScreen(XP, YP, XM, YM, 300); 

    int x=0; // valeur X d'appui tactil
    int y=0; // valeur y d'appui tactil
    int z=0; // intensitée d'appui
    
    unsigned long button_delay;          // delay of push buttom
    #define BUTTON_DELAY 200    // delay filter for the buttom 
    
    #define DELAY_REFRESH_SCREEN         5000
    #define DELAY_REFRESH_SCREEN_SECONDS 5
    unsigned long refresh_datas=0;   // delay to refresh screen and data, every 10 seconds*
    
    byte          refresh_demand=1;
    #define       REFRESH_SCREEN    0  
    #define       REFRESH_DATA      1   
    #define       UPDATE_SCREEN     2
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

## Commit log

2020-06-08 Update vmc board
    [CompteurEnergieRadio.sch]
2020-12-22 Correction on PCB and add cover stl file
    [CompteurEnergieRadio.kicad_pcb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]
2020-12-22 add new file for pcb
    [Cache box carte VMC..stl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]
2021-02-06 add documentation to extend I2C bus

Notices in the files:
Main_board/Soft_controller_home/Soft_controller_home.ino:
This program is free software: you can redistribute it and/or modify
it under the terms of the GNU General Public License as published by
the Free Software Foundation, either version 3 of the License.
